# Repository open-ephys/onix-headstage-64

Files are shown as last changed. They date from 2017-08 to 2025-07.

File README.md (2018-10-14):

# headstage-64
Serialized, multifunction headstage for small rodents. Designed to function
with [eib-64](../eib-64/README.md).

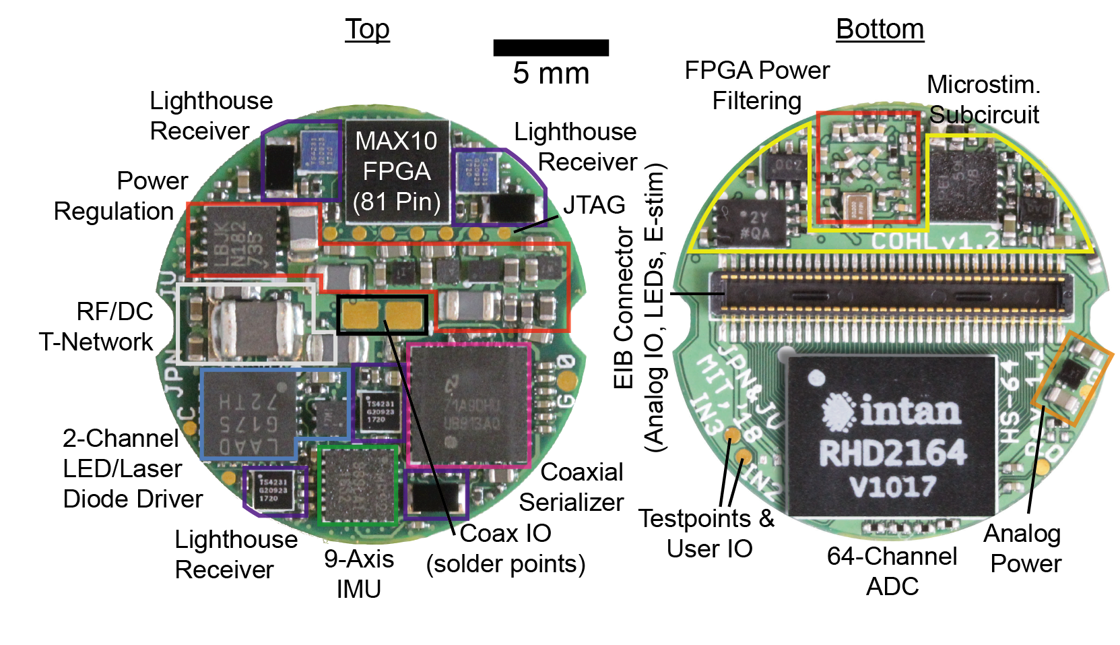
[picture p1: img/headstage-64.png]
headstage-64


## Gerber Files
{% include gerber_layers.md %}

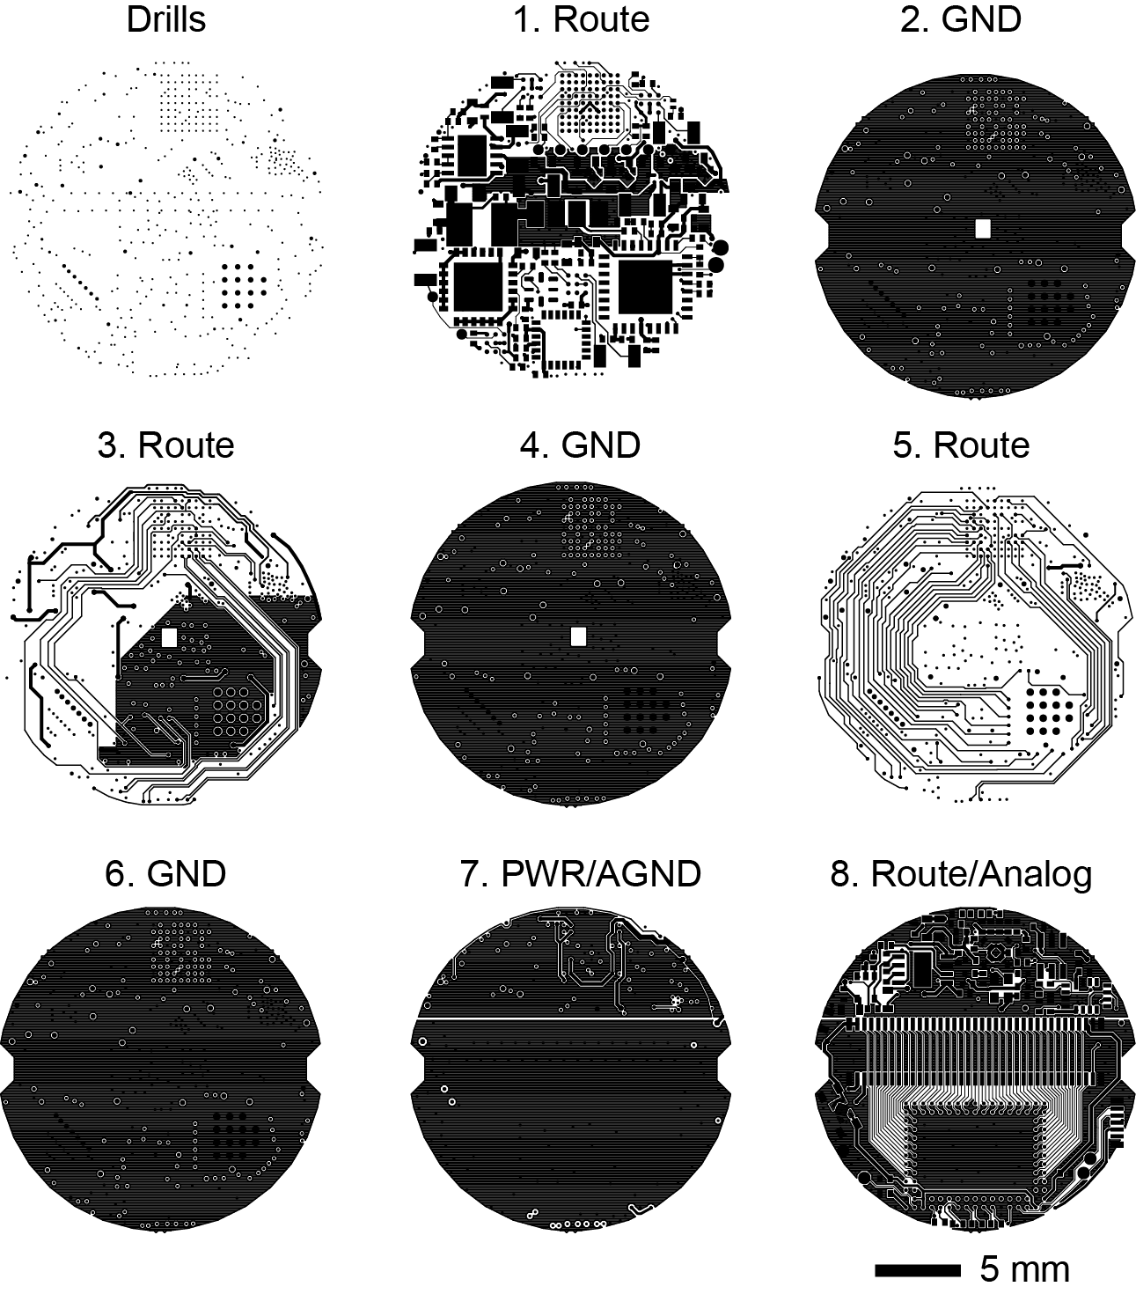
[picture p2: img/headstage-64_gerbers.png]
headstage-64 Gerbers


## Bill of Materials
The BOM is located on [this google
sheet](https://docs.google.com/spreadsheets/d/1F-KWcdvH_63iXjZf0cgCfDiFX6XXW3qw6rlR8DZrFpQ/edit#gid=138167638).

## FPGA Pinout
The FPGA pinout is located on [this google
sheet](https://docs.google.com/spreadsheets/d/1oJoQ89dJNL9LIiTrRnwJ_9KGiLzJ53Tju5Lfchuvsb0/edit#gid=2100166621).

## Connector Pinout
The headstage connector pinout (ADC input mapping, stimulation connections,
etc) is located on [this google
sheet](https://docs.google.com/spreadsheets/d/11wRDYOqHN5lPb03yUdfXfK0zvaDYsVetplaNK-R90Gg/edit#gid=663991061)

## License
Copyright Jonathan P. Newman, Jakob Voigts 2017.

This documentation describes Open Hardware and is licensed under the
CERN OHL v.1.2.

You may redistribute and modify this documentation under the terms of the CERN
OHL v.1.2. (http://ohwr.org/cernohl). This documentation is distributed WITHOUT
ANY EXPRESS OR IMPLIED WARRANTY, INCLUDING OF MERCHANTABILITY, SATISFACTORY
QUALITY AND FITNESS FOR A PARTICULAR PURPOSE. Please see the CERN OHL v.1.2 for
applicable conditions

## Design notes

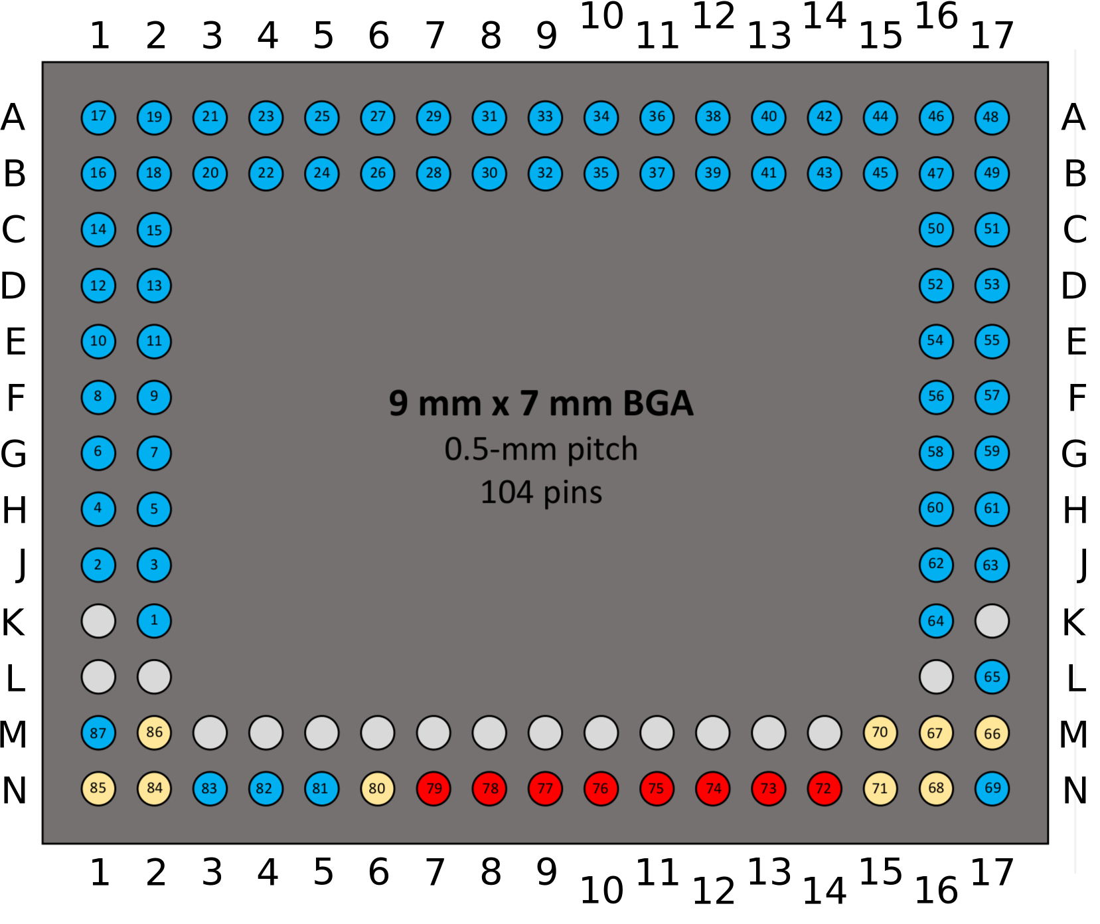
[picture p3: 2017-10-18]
datasheets/rhd2164_bga-pinout.png

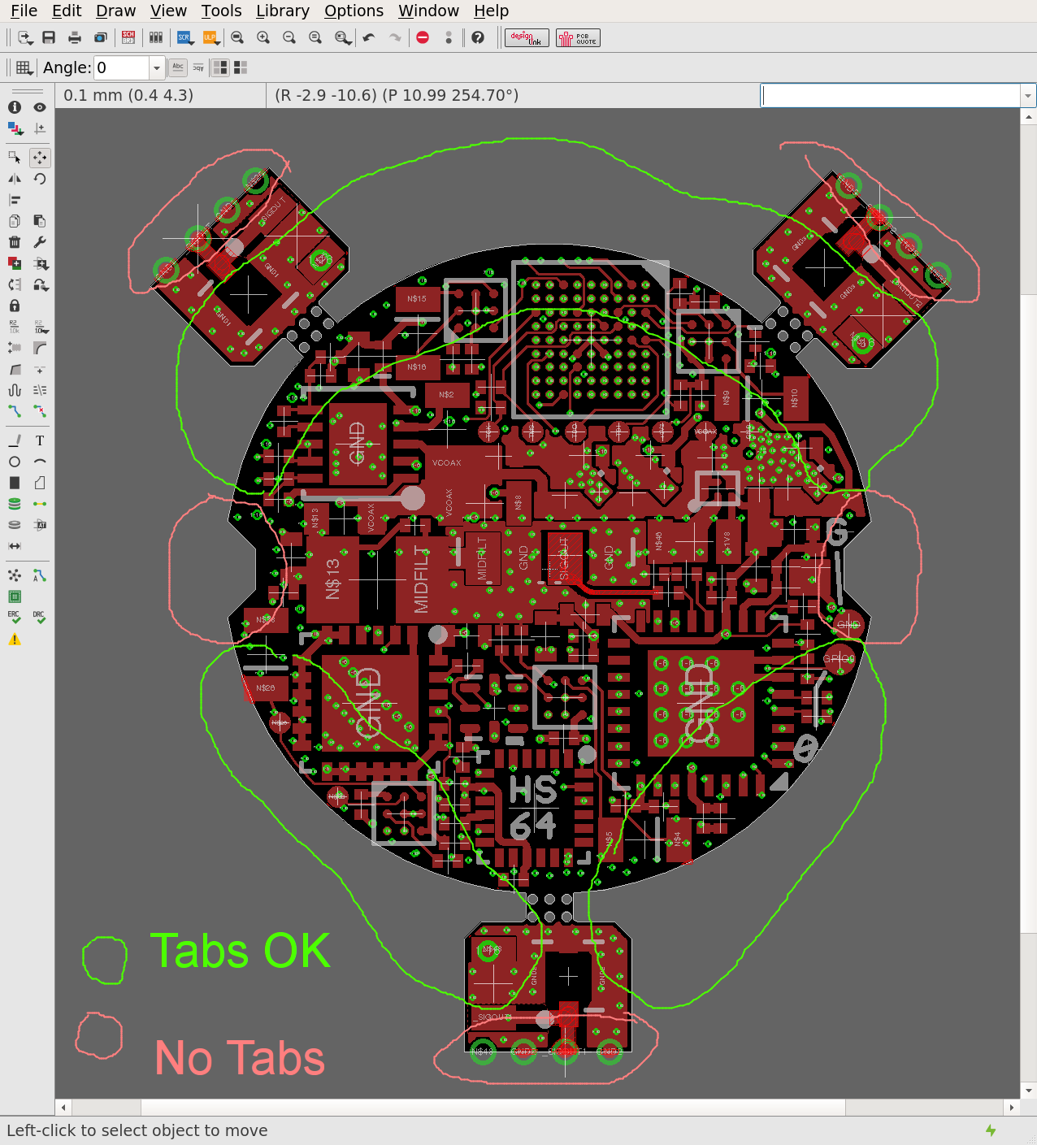
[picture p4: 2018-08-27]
gerber/README_tab-placement.png

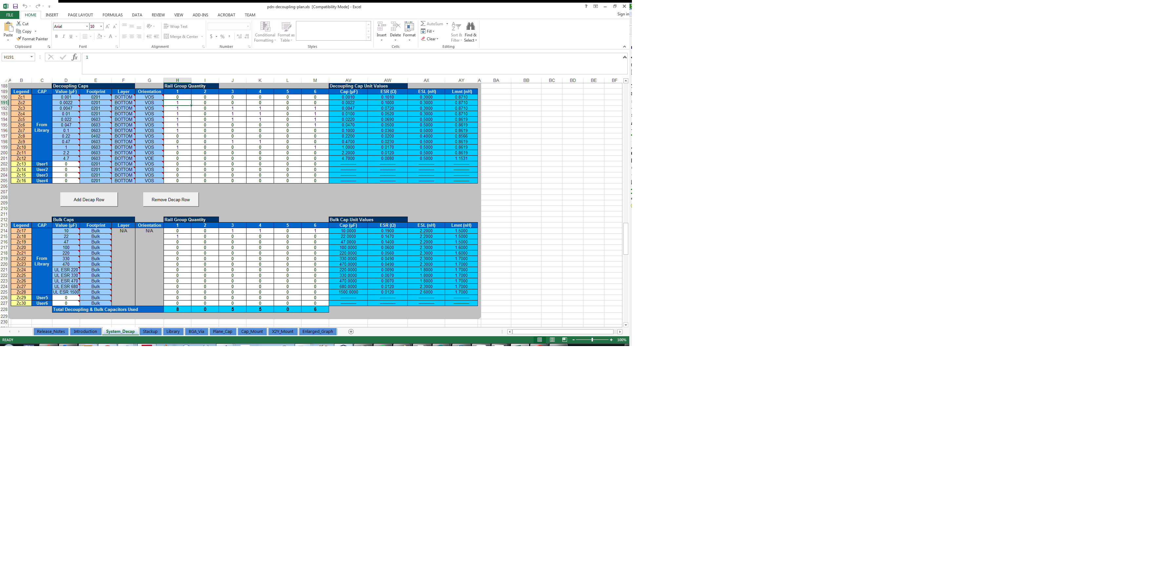
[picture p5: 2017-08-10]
decoupling-capacitors/max10-decoupling-plan.png

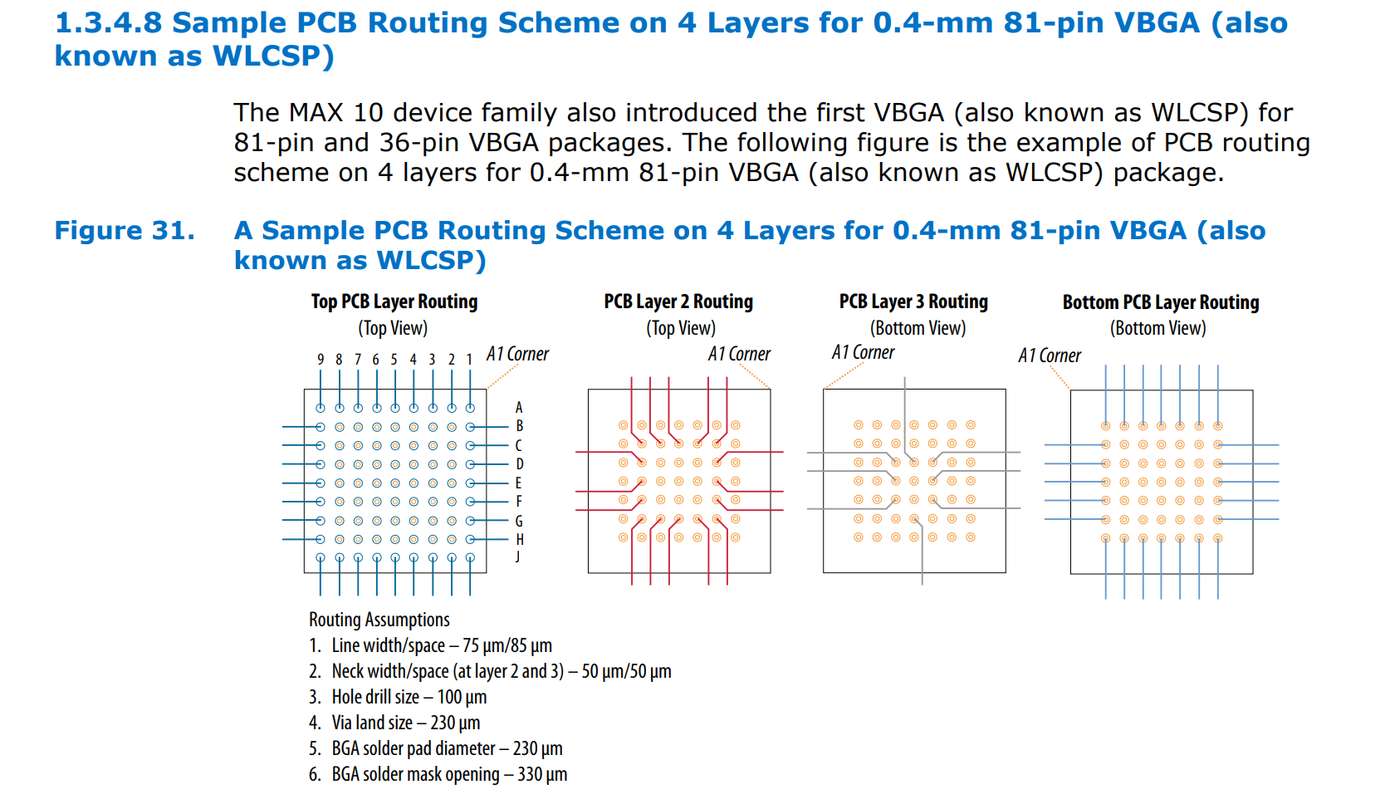
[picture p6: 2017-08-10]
datasheets/MAX10_V81_WLCSP_routing_scheme.png

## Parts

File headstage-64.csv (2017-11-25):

Qty | Value | Device | Package | Parts | Description | PARTNO | PARTNP | TP_SIGNAL_NAME
3 |  | PHOTODIODE_0805T | 0805T | D1, D2, D3
1 |  | PINHD-2X35+4_DF40-70HEAD | DF40-70HEAD | U$1
5 |  | TPB0.4MM | B0.4MM | TP3, TP4, TP5, TP6, TP12 | Test pad
3 |  | TPTP06R | TP06R | TP7, TP9, TP11 | Test pad
8 | 0.1uF | C_0201T | 0201T | C36, C48, C56, C58, C60, C61, C64, C67 | Capacitor
1 | 0.1uF | C_0201T | 0201T | C10 | Capacitor |  | CL03A104KA3NNNC
6 | 0.1uF | C_0201T | 0201T | C2, C4, C6, C12, C13, C70 | Capacitor | C0603X5R1C104K030BC
1 | 0.1uF | C_0201T | 0201T | C51 | Capacitor | C1005X7R1H104K050BB
5 | 0.1uF | C_0201T | 0201T | C7, C8, C11, C20, C21 | Capacitor | CL03A104KA3NNNC
1 | 0.1uF | C_0402T | 0402T | C26 | Capacitor | C0603X5R1C104K030BC
2 | 0.22uF | C_0402T | 0402T | C17, C18 | Capacitor | UMK105BJ224KV-F
3 | 0.47uF | C_0201T | 0201T | C40, C45, C72 | Capacitor | GRM033R60J474KE90D
4 | 100 | R_0201T | 0201T | R26, R27, R28, R29 | Resistor
1 | 100k | R_0201T | 0201T | R20 | Resistor
1 | 10M08DC | 10M08DC_VBGA | VBGA81-4X4 | U11
13 | 10k | R_0201T | 0201T | R4, R5, R17, R18, R19, R23, R30, R31, R32, R34, R35, R36, R38 | Resistor
9 | 10nF | C_0201T | 0201T | C27, C38, C43, C47, C49, C50, C57, C62, C65 | Capacitor
1 | 10nF | C_0201T | 0201T | C30 | Capacitor | CL03A105MP3ZSNH
1 | 10nF | C_0201T | 0201T | C66 | Capacitor | CL03B103KP3NNNC
1 | 10pF | C_0201T | 0201T | C19 | Capacitor
3 | 10uF | C_0402T | 0402T | C22, C24, C42 | Capacitor | CL05A106MQ5NUNC
4 | 15k | R_0201T | 0201T | R1, R2, R3, R37 | Resistor
2 | 1M | R_0201T | 0201T | R9, R11 | Resistor
3 | 1k | R_0201T | 0201T | R14, R15, R33 | Resistor
7 | 1uF | C_0201T | 0201T | C1, C3, C5, C46, C55, C68, C74 | Capacitor | CL03A105MP3ZSNH
7 | 1uF | C_0402T | 0402T | C14, C15, C16, C23, C54, C69, C75 | Capacitor | CL05A105KO5NNNC
1 | 2.2nF | C_0201T | 0201T | C35 | Capacitor
1 | 220 | R_0201T | 0201T | R7 | Resistor
4 | 22nF | C_0201T | 0201T | C33, C39, C44, C71 | Capacitor
1 | 22uF | C_0402T | 0402T | C53 | Capacitor | CL05A226MQ5QUNC
1 | 22uF | C_0402T | 0402T | C41 | Capacitor | CL05A226MQ6ZUN8
2 | 2k | R_0201T | 0201T | R24, R25 | Resistor
2 | 4.7k | R_0201T | 0201T | R21, R22 | Resistor
4 | 4.7nF | C_0201T | 0201T | C29, C31, C32, C37 | Capacitor
1 | 4.7uF | C_0402T | 0402T | C25 | Capacitor | CL05A475MO5NUNC
2 | 4.7uF | C_0402T | 0402T | C59, C63 | Capacitor | GRM155R61A475MEAAD
1 | 470pF | C_0201T | 0201T | C9 | Capacitor
2 | 47nF | C_0201T | 0201T | C28, C34 | Capacitor
1 | 47nF | C_0201T | 0201T | C52 | Capacitor | C1005X7R1H473K050BB
1 | 49.9 | R_0201T | 0201T | R16 | Resistor
1 | 5.49k | R_0201T | 0201T | R6 | Resistor
1 | 50 | R_0201T | 0201T | R13 | Resistor
1 | 600 | R_0201T | 0201T | R8 | Resistor
1 | 83.3k | R_0201T | 0201T | R10 | Resistor
1 | 90.9k | R_0201T | 0201T | R12 | Resistor
1 | ADG1401 | ADG140X_LFCSP | LFCSP8-2X3 | U8 |  | ADG1401BCPZ
3 | BLM15PX601SN1D | L_0402T | 0402T | L5, L6, L7 | Inductor | BLM15PX601SN1D
1 | BLM18KG601SN1D | L_0603T | 0603T | L12 | Inductor
1 | CAT4016_QFN | CAT4016_QFN | QFN24-4X4 | U3 |  | CAT4016HV6-GT2
1 | CBC3225T101MR | L_1210T | 1210T | L4 | Inductor
1 | CIG21L4R7MNE | L_0805T | 0805T | L3 | Inductor
1 | DAC5311 | DAC5311 | SC70 | U13
1 | DS90UB913A_WQFN | DS90UB913A_WQFN | WQFN32-5X5 | U19
1 | GND_LINK_0201 | GND_LINK_0201 | 0201_LINK | J3
1 | HEADSTAGE64_EDGE-MOUNT | HEADSTAGE64_EDGE-MOUNT | HEADSTAGE64-EDGE-MOUNT_PADS | J1
1 | HEADSTAGE64_EDGE-MOUNT_CASTELLATED | HEADSTAGE64_EDGE-MOUNT_CASTELLATED | HEADSTAGE64-EDGE-MOUNT_CASTELLATED | J2
1 | INA826 | INSTRUMENTAMP_PWSON | PWSON-N8-3X3 | U15 |  | INA826AIDRGR
1 | LT3463 | LT3463 | DFN103X3 | U12
2 | MLZ2012M100WT000 | L_0805T | 0805T | L1, L2 | Inductor
1 | MPU9250_QFN_NO-PAD | MPU9250_QFN_NO-PAD | QFN24-3X3_NO-PAD | U2
1 | OPA170 | OPAMP_PDSO | PDSO-N5 | U4 |  | OPA170AIDBVR
1 | RHD2164_COB3 | RHD2164_COB3 | RHD2164_COB3 | U7 | Intan Technologies RHD2164 chip
1 | TLV70712 | TLV707 | X2SON | U17
1 | TLV70718 | TLV707 | X2SON | U10
1 | TLV70725 | TLV707 | X2SON | U9
1 | TLV70733 | TLV707 | X2SON | U18
1 | TPL0501_UQFN | TPL0501_UQFN | UQFN | U25 |  | TPL0501-100RSER
4 | TS4231 | TS4231 | WLCSP3X3 | U1, U5, U6, U14
2 | VCC | TPB0.3MM | B0.3MM | TP8, TP10 | Test pad
1 | VCC | TPB0.4MM | B0.4MM | TP1 | Test pad
1 | VSKY05401006 | S-DIODE_0402T | 0402T | D4 | Schottky Diode
1 | X.FL-R-SMT-1 | COAX_XFL | X_FL_R_SMT_1(02) | X1 | COAX CONNECTOR
2 | XZVGR155W | LED_0201T | LED-0201T | D5, D6 | Surface mount LED
1 | gnd | TPB0.4MM | B0.4MM | TP2 | Test pad

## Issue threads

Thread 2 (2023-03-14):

Add standardized manufacturing files for test board

ChucklesOnGitHub, 2023-03-14:
For autonomous manufacturing, which might require part changes

If new repo is created for the test-board   #1 , then put this issue there

jonnew, 2025-07-22:
This board is replaced with

Closed 2025-07-22.

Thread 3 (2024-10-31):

Schematic label typo

ChucklesOnGitHub, 2024-10-31:
The schematic information table inside file "headstage-64_schematic.pdf" in branch rev-1.3B mistakenly reads "1.2B", and should read "1.3B" otherwise it is impossible to know the version with the file alone

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

Closed 2025-07-23.

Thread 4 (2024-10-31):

Release 1.3B missing?

ChucklesOnGitHub, 2024-10-31:
Current production files are in Branch: rev-1.3B, it would be helpful to have them released as rev-1.3B after fixing https://github.com/open-ephys/onix-headstage-64/issues/3.

This is to address that the schematics of the headstages users now have in their hands are not easily findable.

You might also want to keep version 1.4 (now in main) as a development branch, since it was never produced.

Closed 2025-07-23.

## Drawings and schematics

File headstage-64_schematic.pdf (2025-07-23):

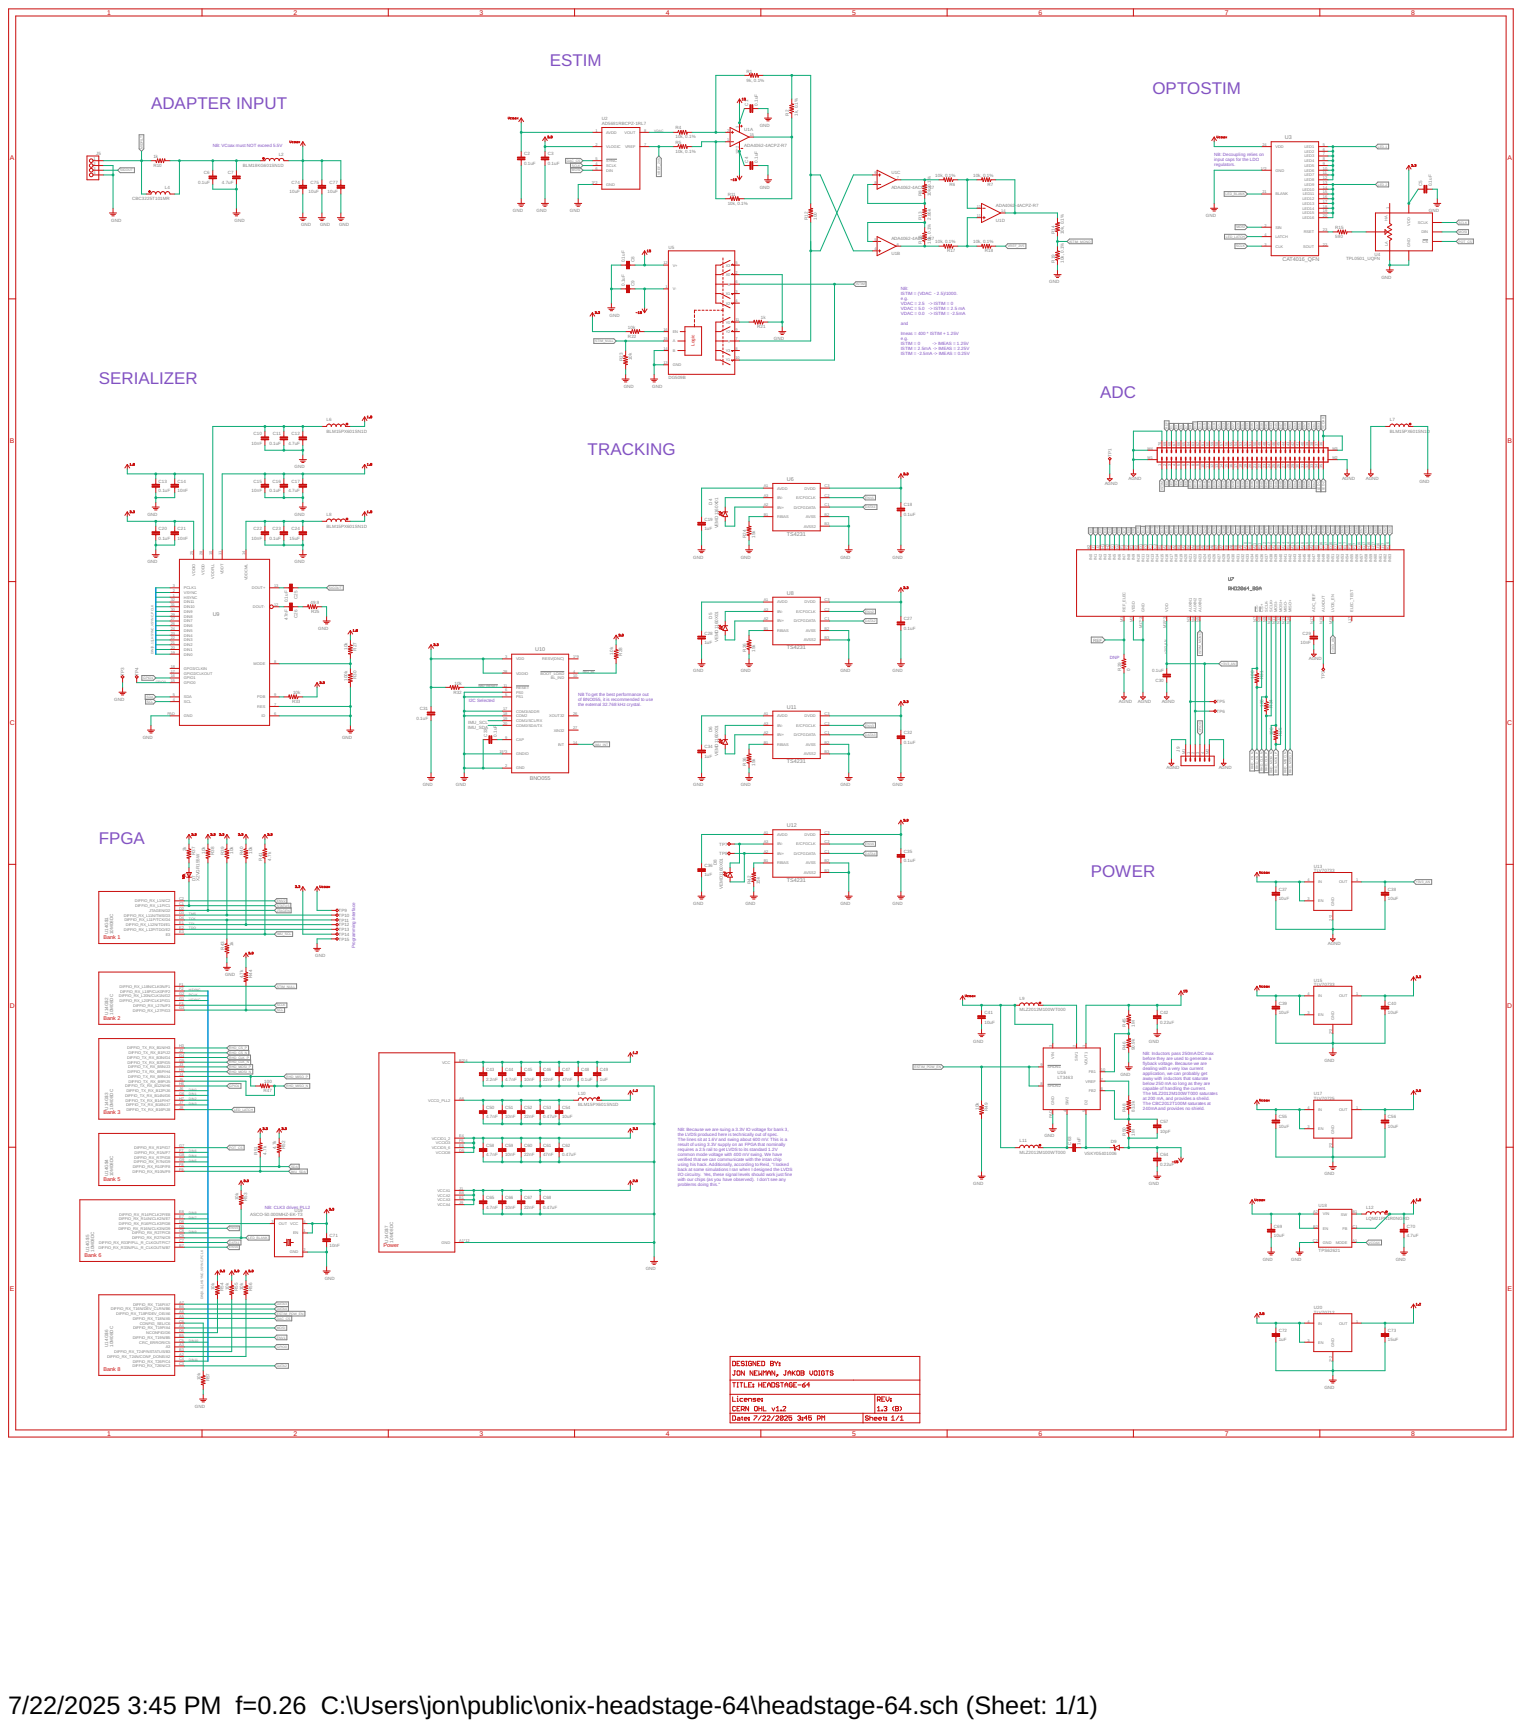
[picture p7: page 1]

NB: VCoax must NOT exceed 5.5V

NB: Decoupling relies on
input caps for the LDO

ISTIM = (VDAC - 2.5)/1000. e.g. VDAC = 2.5 -> ISTIM = 0 VDAC = 5.0 -> ISTIM = 2.5 mA

CS- N7 CS+ N8 SCLK- N9 SCLK+ N10 MOSI- N11

DIN[0..11],HSYNC,VSYNC,PCLK

the external 32.768 kHz crystal.

NB: Inductors pass 250mA DC max before they are used to generate a

flyback voltage. Because we are
dealing with a very low current application, we can probably get away with inductors that saturate

below 250 mA so long as they are
capable of handling the current. The MLZ2012M100WT000 saturates at 200 mA, and provides a sheild. The CBC2012T100M saturates at 240mA and provides no shield.

NB: Because we are suing a 3.3V IO voltage for bank 3,
the LVDS produced here is technically out of spec. The lines sit at 1.6V and swing about 600 mV. This is a

result of using 3.3V supply on an FPGA that nominally
requires a 2.5 rail to get LVDS to its standard 1.2V
common mode voltage with 400 mV swing. We have
verified that we can communicate with the intan chip
using his hack. Additionally, according to Reid, "I looked
back at some simulations I ran when I designed the LVDS
I/O circuitry. Yes, these signal levels should work just fine with our chips (as you have observed). I don't see any problems doing this."

7/22/2025 3:45 PM f=0.26 C:\Users\jon\public\onix-headstage-64\headstage-64.sch (Sheet: 1/1)

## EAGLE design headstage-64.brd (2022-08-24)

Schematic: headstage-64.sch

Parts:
C1: 0.1uF; 0201T; PARTNP CL03A104KA3NNNC
C2, C3, C5, C6, C18, C27, C32, C33, C35: 0.1uF; 0201T; PARTNO C0603X5R1C104K030BC
C4, C8, C9: 0.1uF; 0201T; PARTNO CL03A104KA3NNNC
C7: 4.7uF; 0402T; PARTNO CL05A475MO5NUNC
C10, C14, C15, C21, C22, C45, C51, C59, C66, C71: 10nF; 0201T
C11, C13, C16, C20, C23, C30, C31, C48: 0.1uF; 0201T
C12, C17: 4.7uF; 0402T; PARTNO GRM155R61A475MEAAD
C19, C28, C34, C36, C49: 1uF; 0201T; PARTNO CL03A105MP3ZSNH
C24: 15uF; 0402T; PARTNO CL05A226MQ5QUNC
C25: 0.1uF; 0201T; PARTNO C1005X7R1H104K050BB
C26: 47nF; 0201T; PARTNO C1005X7R1H473K050BB
C29: 10nF; 0201T; PARTNO GRM033R71E103KE14D
C37, C39, C41, C55, C69: 10uF; 0402T; PARTNO CL05A105KO5NNNC
C38, C40, C54, C56: 10uF; 0402T; PARTNO CL05A106MQ5NUNC
C42, C64: 0.22uF; 0402T; PARTNO UMK105BJ224KV-F
C43: 2.2nF; 0201T
C44, C50, C58, C65: 4.7nF; 0201T
C46, C52, C60, C67: 22nF; 0201T
C47, C61: 47nF; 0201T
C53, C62, C68: 0.47uF; 0201T; PARTNO GRM033R60J474KE90D
C57: 10pF; 0201T
C63, C72: 1uF; 0402T; PARTNO CL05A105KO5NNNC
C70: 4.7uF; 0402T; PARTNO CL05A105KO5NNNC
C73: 15uF; 0402T; PARTNO CL05A226MQ6ZUN8
C74, C75, C77: 10uF; 0402T; PARTNO CL05A475MO5NUNC
D4, D5, D6, D8: VEMD1160X01; 0805PT
D7: XZVGR155W; LED-0201T
D9: VSKY05401006; CLP1006-2L
J5: PINHD-1X4HEADSTAGE64_DAUGHTER-CARD; HEADSTAGE-64-DAUGHTER-CARD
J8: DF40C-70DP-0.4V(51); DF40-70HEAD-LESS-SILK
J9: PINHD-1X5_HALF_CONNECTOR; DF40-10HEAD_HALF
L2: BLM18KG601SN1D; 0603T
L4: CBC3225T101MR; 1210T
L6, L7, L8, L10: BLM15PX601SN1D; 0402T; PARTNO BLM15PX601SN1D
L9, L11: MLZ2012M100WT000; 0805T
L12: LQM21PN1R0NGRD; 0805T
R1: 9k, 0.1%; 0201T
R2: 1k, 0.1%; 0201T
R4, R5, R6, R7, R8, R11, R14, R16, R17, R18, R19: 10k, 0.1%; 0201T
R10, R21, R43: 1k; 0201T
R12, R31, R34, R35, R47: 100; 0201T
R13: 2.86k; 0201T
R15: 590; 0201T
R22, R23, R27, R28, R32, R33, R38, R39, R40, R49, R53, R54, R55, R56, R57: 10k; 0201T
R24, R26, R36, R42: 15k; 0201T
R25: 49.9; 0201T
R29: 0; 0201T
R30: 100k; 0201T
R37: 2k; 0201T
R41, R44, R51, R52: 4.7k; 0201T
R45, R50: 1M; 0201T
R46: 90.9k; 0201T
R48: 83.3k; 0201T
TP1, TP2, TP5, TP6: VCC; TP07R
TP3, TP4: TPTP09R; TP09R
TP7, TP8, TP9, TP10, TP11, TP12, TP13: TPTP06R; TP06R
TP14: gnd; TP06R
TP15: VCC; TP06R
U1: ADA4062-4ACPZ-R7; CP_16_27-L
U2: AD5681RBCPZ-1RL7; CP_8_10-L
U3: CAT4016_QFN; QFN24-4X4; PARTNO CAT4016HV6-GT2
U4: TPL0501_UQFN; UQFN; PARTNO TPL0501-100RSER
U5: DG509B; MQFN16-1.8X2.6
U6, U8, U11, U12: TS4231; WLCSP3X3
U7: RHD2064_BGA; BGA104_0.5MM
U9: DS90UB913A_WQFN; WQFN32-5X5
U10: BNO055; LGA-28-3.8X5.2
U13, U15: TLV70733; X2SON
U14: 10M08DC; VBGA81-4X4
U16: LT3463; DFN103X3
U17: TLV70725; X2SON
U18: TPS62621; XBGA6_1.2X0.8
U19: ASCO-50.000MHZ-EK-T3; ASCO
U20: TLV70712; X2SON

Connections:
!IMU_BL: R28.2, U10.4 (!BOOT_LOAD)
!IMU_RESET: R32.1, U10.11 (!RESET)
$N324: C50.1, C51.1, C52.1, C53.1, C54.1, L10.2, U14.A8 (VCCD_PLL2)
+1V2: C43.1, C44.1, C45.1, C46.1, C47.1, C48.1, C49.1, C73.1, L10.1, U14.B2 (VCC), U14.B9 (VCC), U14.H2 (VCC), U14.H8 (VCC), U20.1 (OUT)
+1V8: C13.1, C14.1, C15.1, C16.1, C17.1, C70.1, L6.1, L8.1, L12.1, R27.1, U9.11 (VDDT), U9.28 (VDDD), U18.C1 (FB)
+2V5: C56.1, C65.1, C66.1, C67.1, C68.1, C72.1, U14.B1 (VCCA3), U14.B8 (VCCA2), U14.J1 (VCCA1), U14.J9 (VCCA4), U17.1 (OUT), U20.3 (EN), U20.4 (IN)
+3V3: C3.1, C5.1, C18.1, C20.1, C21.1, C27.1, C31.1, C32.1, C35.1, C40.1, C58.1, C59.1, C60.1, C61.1, C62.1, C71.1, R22.1, R28.1, R32.2, R33.1, R37.1, R38.1, R39.1, R40.1, R41.2, R44.1, R51.2, R52.1, R53.1, R54.1, R55.1, R56.1, TP14.TP, U2.2 (VLOGIC), U4.7 (VDD), U6.C3 (DVDD), U8.C3 (DVDD), U9.25 (VDDIO), U10.3 (VDD), U10.28 (VDDIO), U11.C3 (DVDD), U12.C3 (DVDD), U14.D5 (VCCIO8), U14.E4 (VCCIO1_2), U14.E6 (VCCIO5_6), U14.F5 (VCCIO3), U15.1 (OUT), U19.1 (EN), U19.4 (VCC)
+3V3_AN: C30.2, C38.1, J9.4 (5), U7.M15 (VDD), U7.M16 (LVDS_EN), U7.N2 (VDD), U7.N15 (VDD), U13.1 (OUT)
+15V0: C1.1, C8.1, C42.1, R45.2, U1.3 (V+), U5.12 (V+), U16.1 (VOUT1)
-15V0: C4.1, C9.1, C57.2, C64.1, D9.A, R50.1, U1.10 (V-), U1.PAD (V-), U5.1 (V-)
AGND: C29.2, C30.1, C37.2, C38.2, J8.70, J8.M1, J8.M2, J8.M4, J9.M1 (1), J9.M2 (6), L7.2, R29.1, TP1.TP, U7.M2 (VESD), U7.M17 (GND), U7.N1 (GND), U7.N6 (GND), U13.2 (GND), U13.PAD (GND)
AUXIN2: J9.2 (3), TP6.TP, U7.N4 (AUXIN2)
AUXIN3: J9.1 (2), TP5.TP, U7.N3 (AUXIN1)
CONFIG_SEL: R57.1, U14.C6 (CONFIG_SEL/C6)
CONF_DONE: R56.2, U14.A2 (DIFFIO_RX_T24N/CONF_DONE/A2)
DAC_CS: U2.5 (!SYNC), U14.A5 (DIFFIO_RX_T18N/A5)
DATA1: U6.C1 (D/CFGDATA), U14.C7 (DIFFIO_RX_R33P/PLL_R_CLKOUTP/C7)
DATA2: U8.C1 (D/CFGDATA), U14.C3 (DIFFIO_RX_T26N/C3)
DATA3: U11.C1 (D/CFGDATA), U14.A7 (DIFFIO_RX_T16P/A7)
DATA4: U12.C1 (D/CFGDATA), U14.B6 (DIFFIO_RX_T16N/DEV_CLRN/B6)
DIN0: U9.19 (DIN0), U14.J6 (DIFFIO_TX_RX_B12P/J6)
DIN1: U9.20 (DIN1), U14.G6 (DIFFIO_TX_RX_B14N/G6)
DIN2: U9.21 (DIN2), U14.H7 (DIFFIO_TX_RX_B14P/H7)
DIN3: U9.22 (DIN3), U14.J7 (DIFFIO_TX_RX_B16N/J7)
DIN4: U9.23 (DIN4), U14.G8 (DIFFIO_RX_R7P/G8)
DIN5: U9.24 (DIN5), U14.G9 (DIFFIO_RX_R7N/G9)
DIN6: U9.26 (DIN6), U14.F7 (DIFFIO_RX_R1N/F7)
DIN7: U9.27 (DIN7), U14.E7 (DIFFIO_RX_R14N/CLK2N/E7)
DIN8: U9.29 (DIN8), U14.E8 (DIFFIO_RX_R14P/CLK2P/E8)
DIN9: U9.30 (DIN9), U14.C8 (DIFFIO_RX_R27P/C8)
DIN10: U9.31 (DIN10), U14.C5 (CRC_ERROR/C5)
DIN11: U9.32 (DIN11), U14.C4 (DIFFIO_RX_T26P/C4)
E0: J8.2, U7.K2 (IN0)
E1: J8.68, U7.J1 (IN1)
E2: J8.3, U7.J2 (IN2)
E3: J8.67, U7.H1 (IN3)
E4: J8.4, U7.H2 (IN4)
E5: J8.66, U7.G1 (IN5)
E6: J8.5, U7.G2 (IN6)
E7: J8.65, U7.F1 (IN7)
E8: J8.6, U7.F2 (IN8)
E9: J8.64, U7.E1 (IN9)
E10: J8.7, U7.E2 (IN10)
E11: J8.63, U7.D1 (IN11)
E12: J8.8, U7.D2 (IN12)
E13: J8.62, U7.C1 (IN13)
E14: J8.9, U7.C2 (IN14)
E15: J8.61, U7.B1 (IN15)
E16: J8.10, U7.A1 (IN16)
E17: J8.60, U7.B2 (IN17)
E18: J8.11, U7.A2 (IN18)
E19: J8.59, U7.B3 (IN19)
E20: J8.12, U7.A3 (IN20)
E21: J8.58, U7.B4 (IN21)
E22: J8.13, U7.A4 (IN22)
E23: J8.57, U7.B5 (IN23)
E24: J8.14, U7.A5 (IN24)
E25: J8.56, U7.B6 (IN25)
E26: J8.15, U7.A6 (IN26)
E27: J8.55, U7.B7 (IN27)
E28: J8.16, U7.A7 (IN28)
E29: J8.54, U7.B8 (IN29)
E30: J8.17, U7.A8 (IN30)
E31: J8.53, U7.B9 (IN31)
E32: J8.18, U7.A9 (IN32)
E33: J8.52, U7.A10 (IN33)
E34: J8.19, U7.B10 (IN34)
E35: J8.51, U7.A11 (IN35)
E36: J8.20, U7.B11 (IN36)
E37: J8.50, U7.A12 (IN37)
E38: J8.21, U7.B12 (IN38)
E39: J8.49, U7.A13 (IN39)
E40: J8.22, U7.B13 (IN40)
E41: J8.48, U7.A14 (IN41)
E42: J8.23, U7.B14 (IN42)
E43: J8.47, U7.A15 (IN43)
E44: J8.24, U7.B15 (IN44)
E45: J8.46, U7.A16 (IN45)
E46: J8.25, U7.B16 (IN46)
E47: J8.45, U7.A17 (IN47)
E48: J8.26, U7.B17 (IN48)
E49: J8.44, U7.C16 (IN49)
E50: J8.27, U7.C17 (IN50)
E51: J8.43, U7.D16 (IN51)
E52: J8.28, U7.D17 (IN52)
E53: J8.42, U7.E16 (IN53)
E54: J8.29, U7.E17 (IN54)
E55: J8.41, U7.F16 (IN55)
E56: J8.30, U7.F17 (IN56)
E57: J8.40, U7.G16 (IN57)
E58: J8.31, U7.G17 (IN58)
E59: J8.39, U7.H16 (IN59)
E60: J8.32, U7.H17 (IN60)
E61: J8.38, U7.J16 (IN61)
E62: J8.33, U7.J17 (IN62)
E63: J8.37, U7.K16 (IN63)
ENV1: U6.C2 (E/CFGCLK), U14.B5 (DIFFIO_RX_T19N/B5)
ENV2: U8.C2 (E/CFGCLK), U14.C2 (DIFFIO_RX_L1N/C2)
ENV3: U11.C2 (E/CFGCLK), U14.D9 (DIFFIO_RX_R16N/CLK3N/D9)
ENV4: U12.C2 (E/CFGCLK), U14.B7 (DIFFIO_RX_R33N/PLL_R_CLKOUTN/B7)
ESTIM_POW_EN: R49.1, U14.A6 (DIFFIO_RX_T18P/DEV_OE/A6), U16.8 (!SHDN2), U16.9 (!SHDN1)
GND: C1.2, C2.2, C3.2, C4.2, C5.2, C6.2, C7.2, C8.2, C9.2, C10.2, C11.2, C12.2, C13.2, C14.2, C15.2, C16.2, C17.2, C18.2, C19.2, C20.2, C21.2, C22.2, C23.2, C24.2, C27.2, C28.2, C31.2, C32.2, C33.1, C34.2, C35.2, C36.2, C39.2, C40.2, C41.2, C42.2, C43.2, C44.2, C45.2, C46.2, C47.2, C48.2, C49.2, C50.2, C51.2, C52.2, C53.2, C54.2, C55.2, C56.2, C58.2, C59.2, C60.2, C61.2, C62.2, C64.2, C65.2, C66.2, C67.2, C68.2, C69.2, C70.2, C71.2, C72.2, C73.2, C74.2, C75.2, C77.2, J5.2, J5.4, L7.1, R19.1, R21.1, R23.2, R24.1, R25.1, R26.1, R30.2, R36.1, R42.1, R43.2, R46.1, R49.2, R57.2, TP3.TP, TP15.TP, U2.3 (GND), U2.PAD (GND), U3.1 (GND), U3.PAD (GND), U4.4 (GND), U4.8 (LA), U5.2 (X0), U5.13 (GND), U5.14 (B), U6.B2 (AVSS), U6.B3 (AVSS2), U8.B2 (AVSS), U8.B3 (AVSS2), U9.6 (ID), U9.7 (RES), U9.PAD (GND), U10.2 (GND), U10.5 (PS1), U10.6 (PS0), U10.15 (GNDIO), U10.16 (GNDIO), U10.17 (COM3/ADDR), U10.18 (COM2), U10.25 (GNDIO), U11.B2 (AVSS), U11.B3 (AVSS2), U12.B2 (AVSS), U12.B3 (AVSS2), U14.A1 (GND), U14.A9 (GND), U14.B4 (GND), U14.D1 (GND), U14.D7 (GND), U14.E5 (GND), U14.E9 (GND), U14.F4 (GND), U14.F6 (GND), U14.H1 (GND), U14.H5 (GND), U14.H9 (GND), U15.2 (GND), U15.PAD (GND), U16.PAD (GND), U17.2 (GND), U17.PAD (GND), U18.C2 (GND), U19.2 (GND), U20.2 (GND), U20.PAD (GND)
GPIO0: J9.3 (4), TP4.TP, U9.15 (GPIO0), U14.A3
GPIO1: U9.16 (GPIO1), U14.H6 (DIFFIO_TX_RX_B12N/H6)
HSYNC: U9.1 (HSYNC), U14.F2 (DIFFIO_RX_L18P/CLK0P/F2)
IMU_INT: U10.14 (INT)
IMU_SCL: R41.1, U10.19 (COM1/SCL/RX), U14.E3
IMU_SDA: R51.1, U10.20 (COM0/SDA/TX), U14.F9 (DIFFIO_RX_R10N/F9)
ISTIM: J8.1, U5.6 (X), U5.10 (Y1)
ISTIM_MONO: R14.1, R19.2, U7.N5 (AUXIN3)
ISTIM_PRE: R12.1, U1.9 (+IN), U5.7 (Y)
JTAGEN: R38.2, U14.D2 (JTAGEN/D2)
LED-1: J8.34, U3.5 (LED1), U3.6 (LED2), U3.7 (LED3), U3.8 (LED4), U3.9 (LED5), U3.10 (LED6), U3.11 (LED7), U3.12 (LED8)
LED-2: J8.35, U3.13 (LED9), U3.14 (LED10), U3.15 (LED11), U3.16 (LED12), U3.17 (LED13), U3.18 (LED14), U3.19 (LED15), U3.20 (LED16)
LED_BLANK: R53.2, U3.21 (BLANK), U14.C9 (DIFFIO_RX_R27N/C9)
LED_LATCH: U3.4 (LATCH), U14.J8 (DIFFIO_TX_RX_B16P/J8)
MIDFILT: J5.1, L4.1, R10.1
MOSI: U2.6 (DIN), U3.2 (SIN), U4.2 (DIN), U14.A4 (DIFFIO_RX_T19P/A4)
unnamed: R15.2, U4.6 (WA)
unnamed: C63.1, L11.1, U16.4 (SW2)
unnamed: C57.1, R48.1, R50.2, U16.6 (FB2)
unnamed: D4.C, U6.A3 (IIN-)
unnamed: D4.A, U6.A2 (IIN+)
unnamed: R24.2, U6.B1 (RBIAS)
unnamed: C19.1, U6.A1 (AVDD)
unnamed: L9.1, U16.2 (SW1)
unnamed: D5.C, U8.A3 (IIN-)
unnamed: D5.A, U8.A2 (IIN+)
unnamed: R26.2, U8.B1 (RBIAS)
unnamed: C28.1, U8.A1 (AVDD)
unnamed: C6.1, C7.1, L2.1, L4.2, R10.2
unnamed: R15.1, U3.23 (RSET)
unnamed: D6.C, U11.A3 (IIN-)
unnamed: D6.A, U11.A2 (IIN+)
unnamed: R36.2, U11.B1 (RBIAS)
unnamed: C34.1, U11.A1 (AVDD)
unnamed: C63.2, D9.C, U16.5 (D2)
unnamed: R1.2, R2.2, R12.2, U1.4 (+IN)
unnamed: R21.2, U5.11 (Y0)
unnamed: R45.1, R46.2, U16.10 (FB1)
unnamed: D8.C, TP7.TP, U12.A3 (IIN-)
unnamed: R48.2, U16.7 (VREF)
unnamed: C25.2, U9.13 (DOUT+)
unnamed: D7.2 (A), R37.2
unnamed: R33.2, U9.9 (PDB)
unnamed: C26.2, U9.12 (DOUT-)
unnamed: C26.1, R25.2
unnamed: R27.2, R30.1, U9.8 (MODE)
unnamed: C10.1, C11.1, C12.1, L6.2, U9.10 (VDDPLL)
unnamed: C22.1, C23.1, C24.1, L8.2, U9.14 (VDDCML)
unnamed: C29.1, U7.N17 (ADC_REF)
unnamed: U14.D8 (DIFFIO_RX_R16P/CLK3P/D8), U19.3 (OUT)
unnamed: D8.A, TP8.TP, U12.A2 (IIN+)
unnamed: TP2.TP, U7.N16 (AUXOUT)
unnamed: R42.2, U12.B1 (RBIAS)
unnamed: C36.1, U12.A1 (AVDD)
unnamed: R22.2, U5.16 (EN)
unnamed: R54.2, U14.D6 (NCONFIG/D6)
unnamed: L12.2, U18.B1 (SW)
unnamed: R1.1, R4.2, U1.2 (+IN)
unnamed: R5.2, R11.1, U1.1 (-IN)
unnamed: R2.1, R11.2, U1.15 (OUT)
unnamed: R16.1, R17.2, U1.6 (OUT)
unnamed: R13.1, R16.2, U1.5 (-IN)
unnamed: R8.1, R13.2, U1.8 (-IN)
unnamed: R6.2, R8.2, U1.7 (OUT)
unnamed: R7.1, R14.2, U1.14 (OUT)
unnamed: R6.1, R7.2, U1.12 (-IN)
unnamed: R17.1, R18.2, U1.11 (+IN)
unnamed: C33.2, U10.9 (CAP)
NSTATUS: R55.2, U14.B3 (DIFFIO_RX_T24P/NSTATUS/B3)
PCLK: U9.3 (PCLK1), U14.G2 (DIFFIO_RX_L20N/CLK1N/G2)
POT_CS: U4.3 (!CS), U14.G7 (DIFFIO_RX_R1P/G7)
REF: J8.69, R29.2, U7.M1 (REF_ELEC)
RHD_CLK_N: R34.1, U7.N9 (SCLK-), U14.G5 (DIFFIO_TX_RX_B3P/G5)
RHD_CLK_P: R34.2, U7.N10 (SCLK+), U14.G4 (DIFFIO_TX_RX_B3N/G4)
RHD_CS_N: R31.1, U7.N7 (!CS!-), U14.J2 (DIFFIO_TX_RX_B1P/J2)
RHD_CS_P: R31.2, U7.N8 (!CS!+), U14.H3 (DIFFIO_TX_RX_B1N/H3)
RHD_MISO_N: R47.1, U7.N13 (MISO-), U14.J5 (DIFFIO_TX_RX_B9P/J5)
RHD_MISO_P: R47.2, U7.N14 (MISO+), U14.J4 (DIFFIO_TX_RX_B9N/J4)
RHD_MOSI_N: R35.1, U7.N11 (MOSI-), U14.H4 (DIFFIO_TX_RX_B5P/H4)
RHD_MOSI_P: R35.2, U7.N12 (MOSI+), U14.J3 (DIFFIO_TX_RX_B5N/J3)
SCL: R44.2, U9.4 (SCL), U14.G3 (DIFFIO_RX_L27P/G3)
SCLK: U2.4 (SCLK), U3.3 (CLK), U4.5 (SCLK), U14.F3 (DIFFIO_RX_L27N/F3)
SDA: R52.2, U9.5 (SDA), U14.F8 (DIFFIO_RX_R10P/F8)
SIGOUT: C25.1, J5.3
STATUS: D7.1 (C), U14.C1 (DIFFIO_RX_L1P/C1)
STIM_NULL: R23.1, U5.15 (A), U14.F1 (DIFFIO_RX_L18N/CLK0N/F1)
TCK: R43.1, TP11.TP, U14.D4 (DIFFIO_RX_L11P/TCK/D4)
TDI: R40.2, TP12.TP, U14.E1 (DIFFIO_RX_L12N/TDI/E1)
TDO: TP13.TP, U14.E2 (DIFFIO_RX_L12P/TDO/E2)
TMS: R39.2, TP10.TP, U14.D3 (DIFFIO_RX_L11N/TMS/D3)
VCOAX: C2.1, C37.1, C39.1, C41.1, C55.1, C69.1, C74.1, C75.1, C77.1, J8.36, J8.M3, L2.2, L9.2, L11.2, TP9.TP, U2.1 (AVDD), U3.24 (VDD), U13.3 (EN), U13.4 (IN), U15.3 (EN), U15.4 (IN), U16.3 (VIN), U17.3 (EN), U17.4 (IN), U18.A1 (MODE), U18.A2 (VIN), U18.B2 (EN)
VDAC: R4.1, U2.8 (VOUT)
VREF_2V5: R5.1, R18.1, U2.7 (VREF)
VSYNC: U9.2 (VSYNC), U14.G1 (DIFFIO_RX_L20P/CLK1P/G1)

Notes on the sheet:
NB: Inductors pass 250mA DC max before they are used to generate a flyback voltage. Because we are dealing with a very low current application, we can probably get away with inductors that saturate below 250 mA so long as they are capable of handling the current. The MLZ2012M100WT000 saturates at 2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
NB: VCoax must NOT exceed 5.5V
Programming interface
ESTIM
OPTOSTIM
SERIALIZER
FPGA
ADC
TRACKING
POWER
NB: Because we are suing a 3.3V IO voltage for bank 3, the LVDS produced here is technically out of spec. The lines sit at 1.6V and swing about 600 mV. This is a result of using 3.3V supply on an FPGA that nominally requires a 2.5 rail to get LVDS to its standard 1.2V common mode voltage with 400 m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
DNP
NB: CLK3 drives PLL2
NB: ISTIM = (VDAC - 2.5)/1000. e.g. VDAC = 2.5 -> ISTIM = 0 VDAC = 5.0 -> ISTIM = 2.5 mA VDAC = 0.0 -> ISTIM = -2.5mA and Imeas = 400 * ISTIM + 1.25V e.g. ISTIM = 0 -> IMEAS = 1.25V ISTIM = 2.5mA -> IMEAS = 2.25V ISTIM = -2.5mA -> IMEAS = 0.25V
I2C Selected
NB To get the best performance out of BNO055, it is recommended to use the external 32.768 kHz crystal.
NB: Decoupling relies on input caps for the LDO regulators.
ADAPTER INPUT

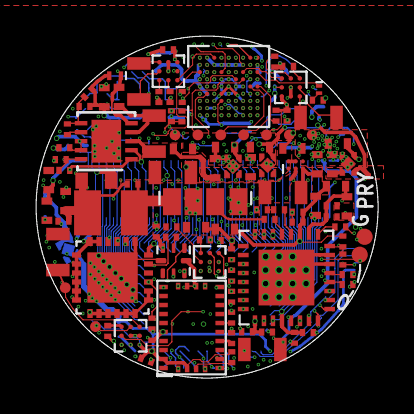
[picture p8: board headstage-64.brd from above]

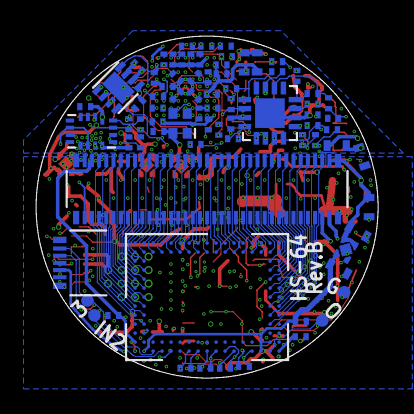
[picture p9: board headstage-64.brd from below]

Board: 8 copper layers, 19.0 x 19.0 mm, 183 parts (77 on the bottom side), 195 nets.

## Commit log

2017-07-30 Started 64-channel mouse headstage
    - Designed to work with new shuttle drives
    - In the middle of layout planning
    [headstage-64.brd, headstage-64.sch]
2017-07-30 Work on headstage-64
    - Electrode routing basically complete
    - LED driver, estim power, estim circuit, and light-house circuits added
    to schematic
    - Playing with component positions to see if 8x8 spartan FPGA can be
    used.
    [headstage-64.brd, headstage-64.sch]
2017-07-30 Started adding spartan6 to headstage-64
    - Incomplete part, just checking spacing
    - Also added estim reset swtich to schematic
    [headstage-64.brd, headstage-64.sch]
2017-07-31 Set 64ch headstage radius to 9.5 mm
    - added cutouts on milling layer for plastic retainers
    - diameter is determined by 2mm stack height
    - moved some packages to leave space for the retainers
    [headstage-64.brd]
2017-07-31 More 64ch Headstage layout
    - Added rough outline of castellated board
    - Added hirose RF connector
    - Moved stim circuit to bottom
    - Moved FPGA to oppose the RHD, to allow for bypass caps under chip
    [headstage-64.brd, headstage-64.sch]
2017-07-31 More 64ch Headstage layout
    -Moved FPGA north to reduce analog area overlap
    -Reduced castellated riser footprint
    [headstage-64.brd]
2017-08-01 Added the complete FPGA to the headstage-64
    - Also added the DC path from the coax connector with some annoyingly
    large inductors
    - Put bypass on LDOs
    - Added pinouts to bipolar power supply shutdown
    [headstage-64.brd, headstage-64.sch]
2017-08-01 Replaced SOD123 s-diode on headstage-64 with 0402.
    [headstage-64.brd, headstage-64.sch]
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2017-08-02 Added digital pot to led driver - Moved one of the lighthouse tracker ics around to make space
    [headstage-64.brd, headstage-64.sch]
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2017-08-03 Added most of the power and bypass elements
    - FPGA power and bypass
    - Serializer power and bypass
    - IMU power and bypass
    [headstage-64.brd, headstage-64.sch]
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2017-08-06 Switched Spartan-6 for 10MAXDC
    - Much smaller footprint, embedded flash, and oscillator.
    - Starting to review power requriements etc
    [headstage-64.brd, headstage-64.sch]
2017-08-06 Some layout updates - Added 2.5V rail - Fit test of switching reg - Moved all LDOs to top side
    [headstage-64.brd, headstage-64.sch]
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2017-08-09 Added X2Y based decoupling - Not sure about lack of small 0201s but sim says its ok - Layout is just to check floor space - Might be able to combine one of the bulk caps
    [headstage-64.brd, headstage-64.sch]
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2017-08-10 Replaced x2y capacitors with multiple 0201 on headstage-64
    - Smaller overall area and easier to place.
    - Schematic improvements and fixes.
    [headstage-64.brd, headstage-64.sch]
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2017-08-10 Added pogo-pin programming contacts
    - Also simplified bulk LDO bypassing by combining large capacitors
    [headstage-64.brd, headstage-64.sch]
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2017-08-11 Layout - Moved bypassing on e stim circuit to appropriate pins - Arranged LDOs - Moved FPGA bypassing out of the way
    [headstage-64.brd]
2017-08-11 More layout and decoupling
    -Added FPGA decoupling at appropriate pins, in round-robin pattern
    -Moved remaining passives next to their ICs
    [headstage-64.brd, headstage-64.sch]
2017-08-12 more layout WIP
    - tried to make the inductive loops on some smaller FPGA decoupling caps smaller
    [headstage-64.brd, headstage-64.sch]
2017-09-20 Added some dog bone routing to fpga - tried out the spacing for dog-bone routing on a few pins
    [headstage-64.brd]
2017-09-21 started some fpga routing - RHD lvds is there - started adding some serdes lines
    [headstage-64.brd, headstage-64.sch]
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2017-09-24 mostly fixed RHD lvds routing - moved vias out from top layer footprints - added decoupling cap and testpoints
    [headstage-64.brd]
2017-09-24 serdes - fpga routing - got most of the DIN signals taken care of - moved some serdes decoupling caps around a bit
    [headstage-64.brd]
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2017-09-25 Fit test for mezzanine connector
    -Added castellated holes part
    -Started routing some signals to mezzanine board
    [headstage-64.brd, headstage-64.sch]
2017-09-26 some more stim section routing - incomplete routing of stim section - added lighthouse ENV inputs to fpga pins
    [headstage-64.brd, headstage-64.sch]
2017-09-27 tightened up boost conv layout a bit
    [headstage-64.brd]
2017-09-27 Headstage-65 schematic nearly complete
    - Some confusion about what signals traverse the edge mount connector
    [headstage-64.brd, headstage-64.sch]
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2017-10-02 Headstage-64 routing nearly complete
    - Some power and bottom side signal routing is needed at top of board
    still
    [headstage-64.brd, headstage-64.sch]
2017-10-02 Initial completed routing of headstage-64
    - Probably still some changes and optimization needed
    - Passes DRC with intentional dimension vilolations
    [headstage-64.brd, headstage-64.sch]
2017-10-03 Fixes during headstage-64 gerber check
    - Added pullup to NCONFIG
    - Realized that DATA4, and ENV1-4 are not routed. At least data4 needs
    to be routed.
    [headstage-64.brd, headstage-64.sch]
2017-10-04 lighthouse tracking ENV routing wip - rough routing for 3 new env signals - added dat signal for 4th tracker
    [headstage-64.brd, headstage-64.sch]
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2017-10-05 Fixes to headstage-64 routing
    - DRC pass
    [headstage-64.brd]
2017-10-09 Changes to pogo JTAG programming dimensions
    - Pins are now separated by 0.05 inches so that standard pins might be
    possible to use
    - There is not much clearance on the headstage-64 so we may still have
    to use tiny pogo pins
    - Fixed JTAG connectivity on headstage-64 by connecting +3V3 to
    VCC(TRGT) pad
    [headstage-64.brd, headstage-64.sch]
2017-10-18 Started a headstage-64 which uses BGA Intan chip
    - I put it in another file to facilitate comparisons with the wirebond
    version
    - It has errors that need to be resolved, but I didn't bother yet
    because we are likely moving the LVDS bank
    [headstage-64_bga.brd, headstage-64_bga.sch]
2017-10-24 Added different options for LVDS termination on headstage-64
    - One uses emmulated LVDS with resistor networks
    - One uses tru LVDS but needs signgifican rerouting
    - Both need rerouting
    [headstage-64_bga_true-lvds.brd, headstage-64_bga_true-lvds.sch]
2017-10-24 intan LVDS re-route WIP - routed LVDS pairs out from fpga, pins need to be swapped to straighten out assignments on intan end - moved R38 out from under fpga to make some room - 2do: have not routed 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
    [headstage-64_bga_true-lvds.brd, headstage-64_bga_true-lvds.sch]
2017-10-25 headsstage routing WIP - mostly done with SE signals, spacing iss till temporary but topology&overall layout should work - LVDS pairs make it to RHD chip, but pins need to be swapped on fpga to simpl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
    [headstage-64_bga_true-lvds.brd, headstage-64_bga_true-lvds.sch]
2017-10-27 finished rough layout-rework of LVDS and SE traces - got all signals to where they belong - 2do: trace spacing for long distance routing is still all over the place - 2do: the fpga escape pattern nee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
    [headstage-64_bga_true-lvds.brd]
2017-11-03 Replaced 1.8V LDO with step-down converter
    - Should take care of thermal issues
    - introduces more routing fun
    - Also, fixed up some of the trace/space issues with Jakob's LVDS
    routing
    [headstage-64_bga_true-lvds.brd, headstage-64_bga_true-lvds.sch]
2017-11-05 Completed routing for true-lvds version of headstage-64
    - GPIO is an unrouted trace that will probably stay that way for a
    air-wire
    - Extensive rework of many portions of board
    - 1.8V is now from a tiny step down converter
    - This board is not production ready, i've started a checklist on slack
    to get it there
    [headstage-64_bga_true-lvds.brd, headstage-64_bga_true-lvds.sch]
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2017-11-06 Headstage-64 routing refinements
    - Update programmer to reflect switchee Vcoax/Gnd positions
    - AGND/GND sprinkles for thermal and noise considerations
    - Route optimization/simplificiation
    [headstage-64.brd]
2017-11-06 small fixes to traces
    [headstage-64.brd]
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2017-11-07 Minimum LDO Vin is 2V
    - The 1.2V LDO was being supplied with 1.8 volts, which will not work
    - Routed the 2.5V LDO to it. This should be OK because neither of these
    are under heavy load and the large step down from Vcoax is spread across
    2 devices.
    [headstage-64.brd, headstage-64.sch]
2017-11-20 Changed RF connector to 2 SMD pads - Micro coax is too fragile- smd pads will allow use of simple mill max pair or similar
    [headstage-64.brd, headstage-64.sch]
2017-11-21 Some changes to new coax interface on headstage-64
    - Traces thicker
    - Copper pours
    - Does not pass DRC
    [headstage-64.brd]
2017-11-21 Fixed lighthouse IC location
    [headstage-64.brd]
2017-11-25 Fixing DRC errors in headstage 64
    - Got rid of castellated daughter board
    - Simplified schematic
    - Produced gerbers
    - Should be about ready to go
    [headstage-64.brd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]
2017-11-25 Routed ENV4 from the forth SteamVR module
    - A couple other ERC fixes
    [headstage-64.brd, headstage-64.sch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]
2017-11-27 fixed some small routing errors - one of the lighthouse IC signals wasnt making it to the fpgs - some small stubs left in V+ layer - relaxed some trace spacing
    [headstage-64.brd]
2017-12-03 Fixed missing 1.8v power intput to serializer in headstage-64
    - Added values to components missing them
    - Completed ERC and DRC
    - Should be ready for fab pending final checks by other ppl
    [headstage-64.brd, headstage-64.sch]
2017-12-07 Moved status LEDs away from serdes tether solder pads - moved one off to the right a bit - moved one next to FPGA, had to shift lighthouse sensor etc down by .2mm to do that. - still getting very min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
    [headstage-64.brd]
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2018-01-20 Updated footprint of headstage-64 s-diode
    - It was too big for the 0402-sized part we are using an prevented
    proper reflow
    [headstage-64.brd, headstage-64.sch]
2018-01-27 Post assembly headstage-64 update
    - Small changes made after assembling first prototype of headstage-64
    - TLVxxx LDO's package/land patterns fixed
    - 0402 diode package fixed
    - Components that we found were likely to short were moved apart
    - Cream/solder mask improvements
    [headstage-64.brd, headstage-64.sch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]
2018-02-03 Added a connection for estim power enable
    - I did not route it yet. I'm going to let other issues accumulate
    before doing that
    [headstage-64.brd, headstage-64.sch]
2018-02-06 Routed the missing estim power trace
    - Fixes issue mentioned in 7940a139
    - Created all gerbers etc
    [headstage-64.brd, headstage-64_via-reduce.brd, headstage-64_via-reduce.sch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]
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2018-04-07 Headstage-64 updates following testing
    - Added 50 MHz crystal oscillator to drive FPGA PLL
    - LED driver now gets serial data via common MOSI line instead of
    dedicated SDO. Clock line is still separate since it acts like the LED
    driver's clock and CS together.
    - LED driver's blank pin is now tied to CRC_ERROR/C5 on FPGA
    - Removed one status LED and instead routed serializer GPIO0 to FPGA
    - Increased size of programming pads
    [headstage-64.brd, headstage-64.sch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]
2018-04-13 Updates due to production questions from speedy
    - Space added between some components
    - 3.3V stub removed from headstage-64
    - Intan AUXOUTs routed to test points on both boards
    - Crystal's re-routed to drive FPGA clock pins that interface with an
    avaialble PLL. Previous routing went to clock pins that had no PLL on
    both designs.
    - Some pins swapping to simplfy routing on both boards.
    [headstage-64.brd, headstage-64.sch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]
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2018-04-15 Lots of small fixes and cleanup
    - Taking care of little issues that have been bothering me
    - Dediated serdes interface board moved to deprecated
    - Non-serialized headstage moved to deprecated
    - Deleted top-level datasheets directory which does not really
    apply to anything anymore
    - Added pdfs versions of board schematics so that eagle is not
    needed to see them.
    - Small fixes to test-boards: High power LEDs moved to bottom to prevent
    blinding ppl. Silkscreen improved. License updated. Etc. Gerbers
    updated.
    - Removed random deprecated design files where I found them.
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2018-05-07 Incrreased the value of the estim discharge resistor
    - Circuit could become unstable if current still being passed when
    analog switch was closed. This fixes this issue.
    [headstage-64.brd, headstage-64.sch]
2018-05-18 Replaced stim null circuit on both headstages
    - ADG140x was replaced with dg509b, which is a 2 circuit 1-to-4 mux.
    This allows the electrode path to be completely disconnected from
    stimulation circuitry during idle periods. During idle periods,
    stimuluation output is shunted to ground through a dummy load so that
    offsets to not develop large voltages during idle periods.
    - Additionally, the inverting node of the estim current source amplifier
    is sent to the intan chip instead of the DAC voltage. This gives a true
    reflection of delivered current rather than just the control signal.
    [headstage-64.brd, headstage-64.sch]
2018-05-21 Minor fixes following headstage-256 assembly
    - Corrected 0201 LED package
    - Moved a couple passives apart to reduce shorts
    [headstage-64.brd, headstage-64.sch]
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2018-07-20 fixed vias to match new stackup
    [headstage-64.brd]
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2018-07-23 More WIP routing on on headstage-64 - tried avoiding the area under the RF connector, still am intersecting the power decoupling section by a bit.
    [headstage-64.brd, headstage-64.sch]
2018-07-24 Routing WIP on headstage-64 -Cleaned up some more traces and swapped pins to move traces out from RF area, still need to clean up routing layer quite a bit
    [headstage-64.brd, headstage-64.sch]
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2018-08-03 Small fixes on headstage64
    [headstage-64.brd]
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2018-08-10 Many fixes to new 8-layer routing
    - Replace ultra thin power traces
    - Proper z on differential pairs
    - Decoupling elements moved to corresponding ICs
    - Remove thin gnd wiring and use planes
    [headstage-64.brd, headstage-64.sch]
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2018-08-16 headstage-64 ready for fabrication
    - Ready for speedy
    - Tiny improvements due to DRC and drill rack check
    - Fabrication files updated
    - Missing gerber files added
    - Gerbv project updated
    [headstage-64.brd, headstage-64.sch, headstage-64_via-reduce.brd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]
2018-08-17 Moved parts around on headstage-64 to increase spaces between pads
    - Tried to jiggle parts around to prevent very closely spaced pads on
    difference signals. Hopefully this will reduce possibily of shorts
    during reflow.
    [headstage-64.brd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]
2018-08-20 Added missing headstage-64 gerber files
    - Missing copper layer 6, 7, and 1-6 drill hits
    - These were missed during 6 layer to 8 layer board conversion
2018-08-27 Many fixes on headstage-64 before fabriation
    - A bit of scary commit because I found significant errors in the board
    - There were redunant MOSI lines and a missing MISO line for the IMU.
    These were fixed. The extra line allowed GPIO1 from serializer to be
    routed to FPGA.
    [headstage-64.brd, headstage-64.sch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]
2018-09-10 Added ESD protection to host board and headstages
    - Host board has a high-voltage RC circuit between isolaed ground planes
    to prevent common-mode voltage accumulation on isolated side
    - TVS diodes are installed on headstage and host board sides to take
    care of ESD events.
    [headstage-64.brd, headstage-64.sch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]
2018-10-01 Replace headstage-64 estim circuit with Howland design
    - Replace in-amp in feedback loop with an (improved) Howland current
    source.
    - +/-2.5 mA stim range
    - Increased resolution of DAC to 12 or 16 depending on specific part
    number.
    - 2.5V center reference provided by DAC. DAC produces 2*2.5V swing.
    - Howland created using one opamp of quad JFET-based opamp. Other 3 are
    used to make instrumentaiton amplifier to measure stim current.
    - No gerbers or spice added yet. Those are to come.
    [headstage-64.brd, headstage-64.sch]
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2018-10-07 headstage-256 rev 1.1 and headstage-64 rev. 1.2
    - These should be ready for fabrication
    - Extensive DRU and manual checking on both designs
    - Howland current source integrated into both designs
    - MPU9250 replace with ICM-20948 on headstage-64 since MPU is deprecated
    - Gerbers update and gerbv project files as well
    - Schematics of both headstages updated
    [headstage-64.brd, headstage-64.sch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]
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2018-11-17 WIP/concept: Swapped in the Bosch BNO055 - This required some major crimes against the DRC but illustrates what might be a viable layout - Major layout and routing revisions are needed - FPGA pinout 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
    [headstage-64_bno55.brd, headstage-64_bno55.sch]
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2018-12-05 Fixed mising vcoax trace on bno55 variant
    [headstage-64_bno55.brd]
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2018-12-21 Fixed swapped resistor values on Howland circuit
    - 9k and 10k resistors where swapped on the Howland current source
    porition of the estim circuit on headstage-256 and headstage-64
    - Also, I added an optional 1/10 Vcoax path to one of the analog inputs
    on headstage-256 to allow the host to monitor supply voltage over long
    cables.
    [headstage-64.brd, headstage-64.sch, headstage-64_via-reduce.brd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]
2019-01-02 Minor changes to headstage-64 while updating BOM
    - stencil size reduced for dfn diode packages to prevent shorting
    [headstage-64.brd, headstage-64.sch, headstage-64_via-reduce.brd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]
2022-02-11 onix-headstage-64 rev. 1.3B
    - This is a patch ("B") on rev. 1.3, the beta-test version, that addresses
    difficulties with assembly and use
    - Assembly differences:
    - R45 has been adjusted right by 0.2 mm
    - C75-77 have been added to address noise leaking from vcoax into
    electrodes.
    - The adapter boards have been removed from the design. This results
    in non-contiguous reference designators, but components names have
    NOT been changed
    - Copper pours have been added to all layers to aid with ease of pcb fab
    and improve thermal performance
    - Thermal reliefs have been added to contacts onto copper pours except
    those where head dissipation is critical (power supplies)
    [headstage-64.brd, headstage-64.sch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]
2022-08-22 Replace every bulk cap on Vcoax with 10uF
    - To reduce near DC noise coming from power over coax and reduce BOM complexity
    [headstage-64.brd, headstage-64.sch]
2022-08-24 22uF caps replaced with 15uF due to ease of sourcing.
    [headstage-64.brd, headstage-64.sch]
2025-07-22 Fix version number on schematic
    [headstage-64.sch]

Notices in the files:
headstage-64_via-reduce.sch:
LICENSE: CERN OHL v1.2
